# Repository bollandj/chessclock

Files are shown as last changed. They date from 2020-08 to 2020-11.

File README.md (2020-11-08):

# chessclock

An electronic chess clock with LED 7-segment displays, based around the ATmega88PA

# Current features include:

- Basic, increment, simple delay, Bronstein delay, hourglass and count up modes

- Start time and increment, delay etc. are fully programmable

- Sound (can be enabled or disabled)

- Adjustable display brightness

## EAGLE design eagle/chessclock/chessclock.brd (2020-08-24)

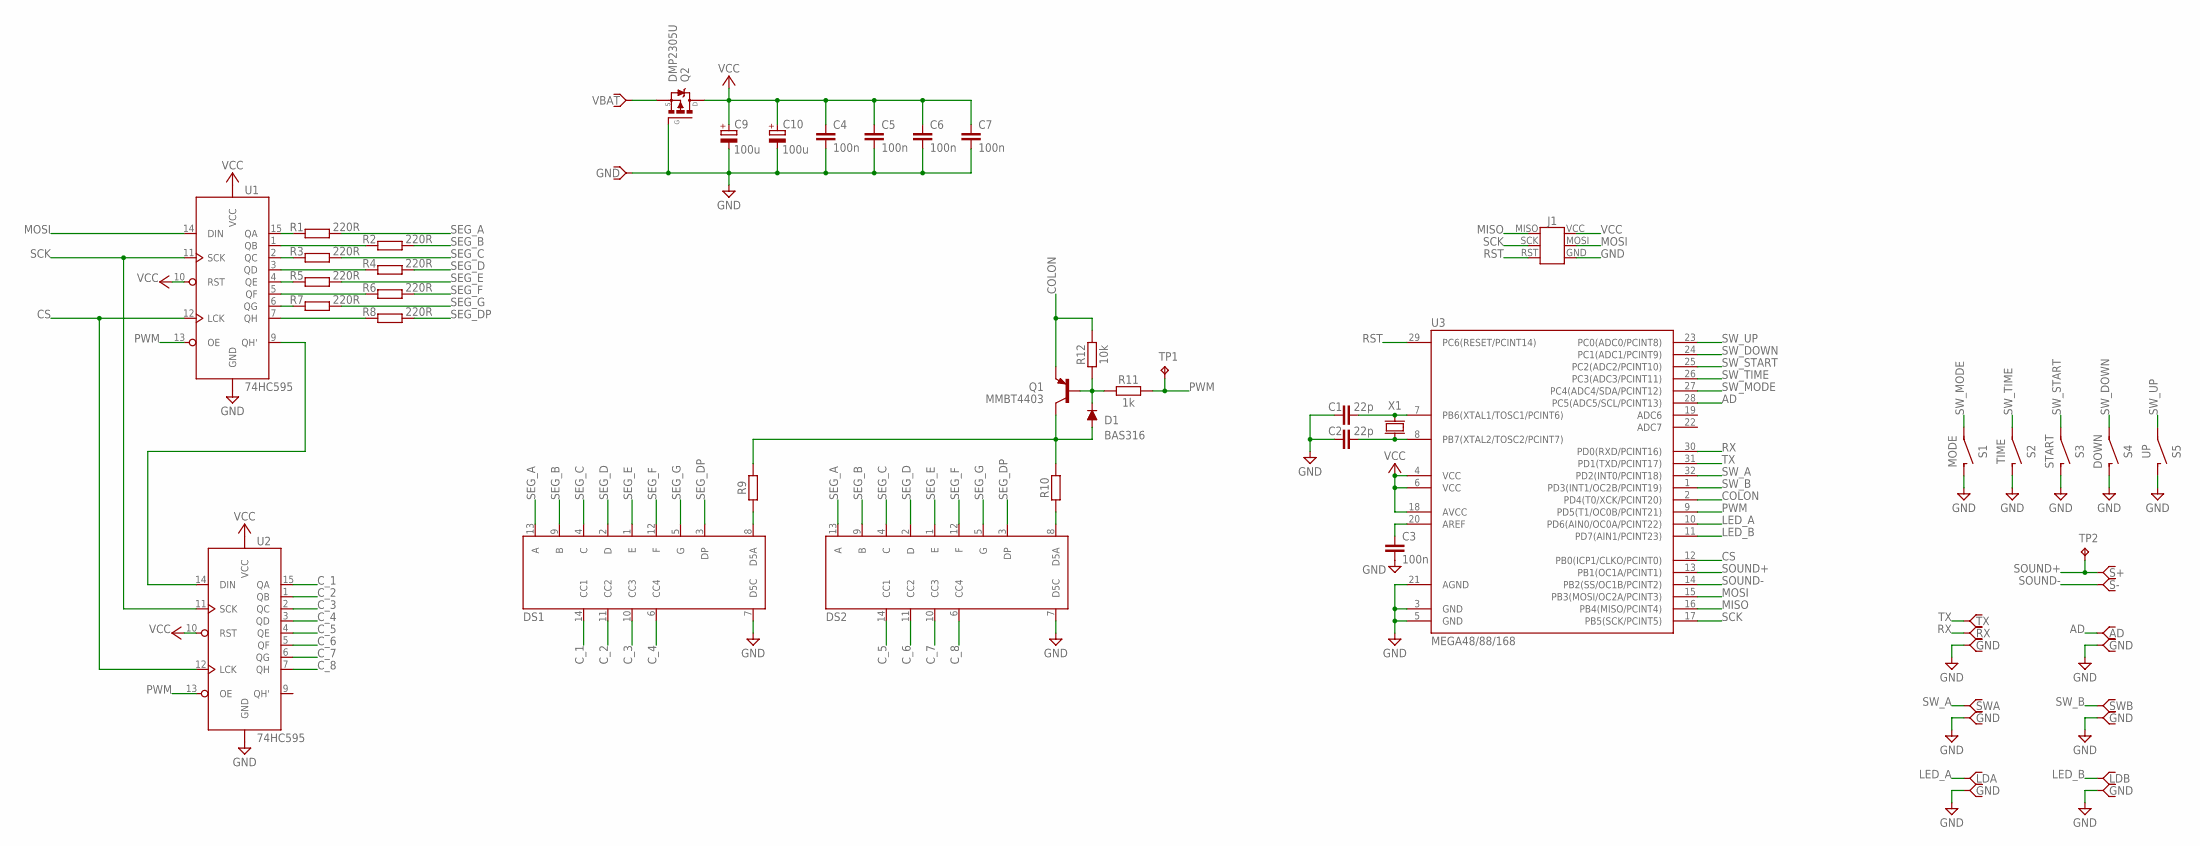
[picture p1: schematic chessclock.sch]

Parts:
C1, C2: 22p; C_0603
C3, C4, C5, C6, C7: 100n; C_0603
C9, C10: 100u; C_E_TH_FLAT_L_5MM
D1: BAS316; SOD323
DS1, DS2: SLR0564FR1C4BD-3.5
J1: AVRISPVERT; AVRISP
P1: SWA; CON_PIN_2MM
P2, P4, P6, P8, P9: GND; CON_PIN_2MM
P3: LDA; CON_PIN_2MM
P5: SWB; CON_PIN_2MM
P7: LDB; CON_PIN_2MM
P10: VBAT; CON_PIN_2MM
P11: S+; CON_PIN_2MM
P12: S-; CON_PIN_2MM
P13, P16: GND; CON_PIN
P14: RX; CON_PIN
P15: TX; CON_PIN
P17: AD; CON_PIN
Q1: MMBT4403; SOT23
Q2: DMP2305U; SOT23
R1, R2, R3, R4, R5, R6, R7, R8: 220R; R_0603
R9, R10: RESISTOR0603; R_0603
R11: 1k; R_0603
R12: 10k; R_0603
S1: MODE; SPST_6X6MM
S2: TIME; SPST_6X6MM
S3: START; SPST_6X6MM
S4: DOWN; SPST_6X6MM
S5: UP; SPST_6X6MM
TP1, TP2: TPTP15R; TP15R
U1, U2: 74HC595; SOIC16
U3: MEGA48/88/168; TQFP32-08
X1: XTAL_32768HZ2X6; XTAL_2X6MM

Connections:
AD: P17.1, U3.28 (PC5(ADC5/SCL/PCINT13))
COLON: Q1.2 (E), R12.2, U3.2 (PD4(T0/XCK/PCINT20))
CS: U1.12 (LCK), U2.12 (LCK), U3.12 (PB0(ICP1/CLKO/PCINT0))
C_1: DS1.14 (CC1), U2.15 (QA)
C_2: DS1.11 (CC2), U2.1 (QB)
C_3: DS1.10 (CC3), U2.2 (QC)
C_4: DS1.6 (CC4), U2.3 (QD)
C_5: DS2.14 (CC1), U2.4 (QE)
C_6: DS2.11 (CC2), U2.5 (QF)
C_7: DS2.10 (CC3), U2.6 (QG)
C_8: DS2.6 (CC4), U2.7 (QH)
GND: C1.2, C2.2, C3.1, C4.1, C5.1, C6.1, C7.1, C9.-, C10.-, DS1.7 (D5C), DS2.7 (D5C), J1.GND (6), P2.1, P4.1, P6.1, P8.1, P9.1, P13.1, P16.1, Q2.1 (G), S1.3 (2), S1.4 (2), S2.3 (2), S2.4 (2), S3.3 (2), S3.4 (2), S4.3 (2), S4.4 (2), S5.3 (2), S5.4 (2), U1.8 (GND), U2.8 (GND), U3.3 (GND), U3.5 (GND), U3.21 (AGND)
LED_A: P3.1, U3.10 (PD6(AIN0/OC0A/PCINT22))
LED_B: P7.1, U3.11 (PD7(AIN1/PCINT23))
MISO: J1.MISO (1), U3.16 (PB4(MISO/PCINT4))
MOSI: J1.MOSI (4), U1.14 (DIN), U3.15 (PB3(MOSI/OC2A/PCINT3))
unnamed: C1.1, U3.7 (PB6(XTAL1/TOSC1/PCINT6)), X1.1
unnamed: C2.1, U3.8 (PB7(XTAL2/TOSC2/PCINT7)), X1.2
unnamed: R2.1, U1.1 (QB)
unnamed: R1.1, U1.15 (QA)
unnamed: R3.1, U1.2 (QC)
unnamed: D1.A, Q1.3 (C), R9.2, R10.2
unnamed: D1.C, Q1.1 (B), R11.1, R12.1
unnamed: C3.2, U3.20 (AREF)
unnamed: R5.1, U1.4 (QE)
unnamed: R4.1, U1.3 (QD)
unnamed: R6.1, U1.5 (QF)
unnamed: R7.1, U1.6 (QG)
unnamed: R8.1, U1.7 (QH)
unnamed: U1.9 (QH'), U2.14 (DIN)
unnamed: DS2.8 (D5A), R10.1
unnamed: DS1.8 (D5A), R9.1
PWM: R11.2, TP1.TP, U1.13 (OE), U2.13 (OE), U3.9 (PD5(T1/OC0B/PCINT21))
RST: J1.RST (5), U3.29 (PC6(RESET/PCINT14))
RX: P14.1, U3.30 (PD0(RXD/PCINT16))
SCK: J1.SCK (3), U1.11 (SCK), U2.11 (SCK), U3.17 (PB5(SCK/PCINT5))
SEG_A: DS1.13 (A), DS2.13 (A), R1.2
SEG_B: DS1.9 (B), DS2.9 (B), R2.2
SEG_C: DS1.4 (C), DS2.4 (C), R3.2
SEG_D: DS1.2 (D), DS2.2 (D), R4.2
SEG_DP: DS1.3 (DP), DS2.3 (DP), R8.2
SEG_E: DS1.1 (E), DS2.1 (E), R5.2
SEG_F: DS1.12 (F), DS2.12 (F), R6.2
SEG_G: DS1.5 (G), DS2.5 (G), R7.2
SOUND+: P11.1, TP2.TP, U3.13 (PB1(OC1A/PCINT1))
SOUND-: P12.1, U3.14 (PB2(SS/OC1B/PCINT2))
SW_A: P1.1, U3.32 (PD2(INT0/PCINT18))
SW_B: P5.1, U3.1 (PD3(INT1/OC2B/PCINT19))
SW_DOWN: S4.1, S4.2 (1), U3.24 (PC1(ADC1/PCINT9))
SW_MODE: S1.1, S1.2 (1), U3.27 (PC4(ADC4/SDA/PCINT12))
SW_START: S3.1, S3.2 (1), U3.25 (PC2(ADC2/PCINT10))
SW_TIME: S2.1, S2.2 (1), U3.26 (PC3(ADC3/PCINT11))
SW_UP: S5.1, S5.2 (1), U3.23 (PC0(ADC0/PCINT8))
TX: P15.1, U3.31 (PD1(TXD/PCINT17))
VBAT: P10.1, Q2.2 (S)
VCC: C4.2, C5.2, C6.2, C7.2, C9.+, C10.+, J1.VCC (2), Q2.3 (D), U1.10 (RST), U1.16 (VCC), U2.10 (RST), U2.16 (VCC), U3.4 (VCC), U3.6 (VCC), U3.18 (AVCC)

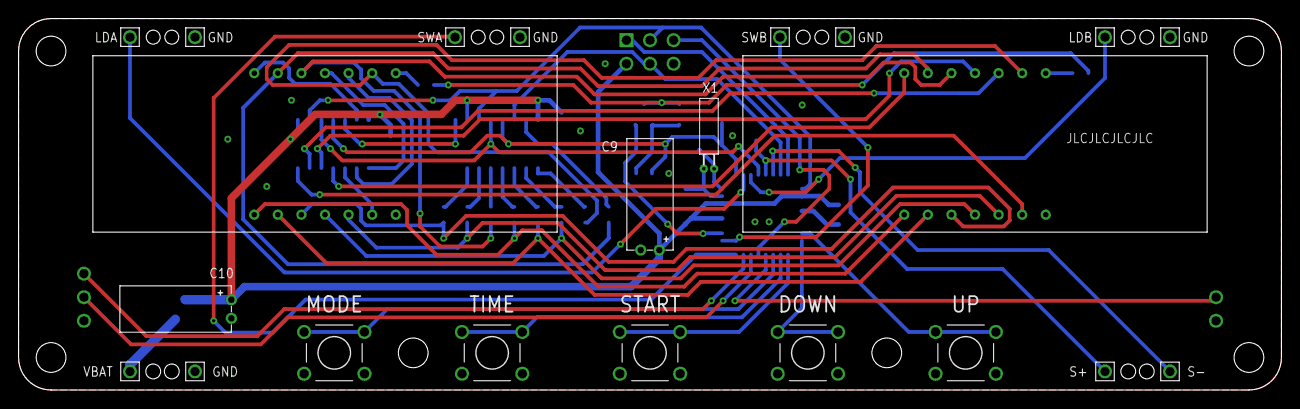
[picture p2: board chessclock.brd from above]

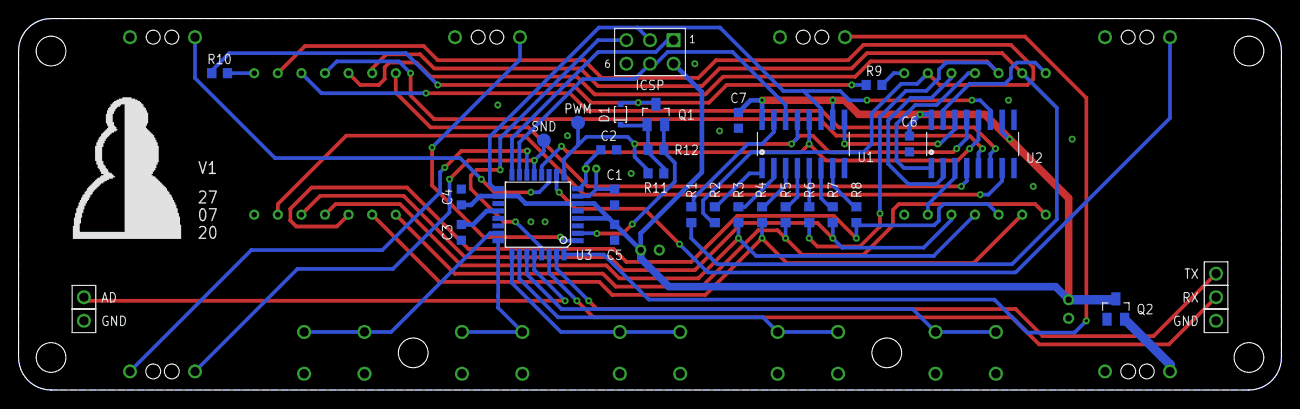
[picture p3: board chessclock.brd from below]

Board: 2 copper layers, 136.0 x 40.0 mm, 55 parts (33 on the bottom side), 56 nets.

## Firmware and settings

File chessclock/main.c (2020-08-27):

/*
 * chessclock.c
 *
 * Created: 03/07/2020 20:23:24
 * Author : Joshua
 */ 

#define F_CPU 8000000UL

#include <avr/io.h>
#include <avr/interrupt.h>
#include <util/delay.h>
#include <avr/pgmspace.h>

#include "display.h"
#include "keys.h"
#include "modes.h"
#include "settings.h"
#include "sound.h"

void init_timer(void)
{
	ASSR = 1<<AS2; // enable asynchronous mode
	
	TCCR2B |= 1<<CS20;  // /1 prescaler
	while (ASSR & 1<<TCR2BUB);     // wait for register update

	

	// TIFR2 = 1<<OCF2A;              // clear interrupt flag	
}

void reset(void)
{	
	/* reset time */
	for (uint8_t i = 0; i < 6; i++)
	{
		playerTime[PLAYER_A][i] = gameConfig.initialTime[i];
		playerTime[PLAYER_B][i] = gameConfig.initialTime[i];
	}

	/* reset ticks */
	playerTicks[PLAYER_A] = 127;
	playerTicks[PLAYER_B] = 127;
}

int main(void)
{			
	/* default to player A as white/starting */
	
	currentPlayer = PLAYER_A;
	
	state = IDLE;
	
	DDRD |= 1<<PD6 | 1<<PD7;
	PORTD &= ~(1<<PD7);
	PORTD |= 1<<PD6;
	
	load_config();
	
	reset();
	
	init_display(deviceConfig.brightness);
	init_keys();
	init_timer();
	init_sound();
	
	sei();
	
    while (1) 
    {					
		scan_keys();		
		
		if ((keyPressed & KEY_MASK) && deviceConfig.soundOn) beep(2);
		
		switch (state)
		{
			/* Idle */
			/* Ready to start a game */
			case IDLE:
			if (keyPressed & START_KEY)
			{
				start_callbacks[gameConfig.gameMode](); // gamemode-specific initialisation
				/* Start counting */
				TIMSK2 = 1<<TOIE2;			
				state = GAME_ACTIVE;
				break;
			}
			else if (keyPressed & MODE_KEY)
			{								
				state = EDIT_MODE;
				break;
			}
			else if (keyPressed & TIME_KEY)
			{
				timeEditCursor = 0;
				blinkMask[0] = 0xFF;
				blinkMask[4] = 0xFF;
								
				state = EDIT_TIME;
				break;
			}
				
			COLON_ON();		
			write_time(0);
			break;
			
			/* Time edit mode */
			/* Edit initial time for one or both players */
			case EDIT_TIME:
			if (keyPressed & START_KEY)
			{
				/* stop blinking */
				blinkMask[timeEditCursor] = 0x00;
				blinkMask[timeEditCursor+4] = 0x00;
				
				/* save settings */
				store_config();
				
				state = IDLE;
				break;	
			}
			else if (keyPressed & TIME_KEY)
			{
				blinkMask[timeEditCursor] = 0x00;
				blinkMask[timeEditCursor+4] = 0x00;
				
				timeEditCursor++;
				timeEditCursor &= 0x03;
				
				blinkMask[timeEditCursor] = 0xFF;
				blinkMask[timeEditCursor+4] = 0xFF;
			}
			else if (keyPressed & (UP_KEY | DOWN_KEY))
			{
				int8_t timeComponent;
				
				uint8_t limit = 5;                    // 9 for units, 5 for seconds
				if (timeEditCursor & 0x01) limit = 9; // even = units, odd = tens
				
				if (keyPressed & UP_KEY)
				{
					timeComponent = ++playerTime[PLAYER_A][timeEditCursor+2];
					if (timeComponent > limit) timeComponent = 0;
				}
				else
				{
					timeComponent = --playerTime[PLAYER_A][timeEditCursor+2];
					if (timeComponent < 0) timeComponent = limit;
				}
				
				gameConfig.initialTime[timeEditCursor+2] = timeComponent;
				
				playerTime[PLAYER_A][timeEditCursor+2] = timeComponent;
				playerTime[PLAYER_B][timeEditCursor+2] = timeComponent;
			}
			
			COLON_ON();	
			write_time(1);
			break;
			
			/* Edit game mode */
			/* Select between different clock modes */
			case EDIT_MODE:			
			if (keyPressed & START_KEY)
			{
				/* save settings */
				store_config();
				
				state = IDLE;
				break;
			}
			else if (keyPressed & MODE_KEY)
			{			
				state++;
				break;
			}						
			else if (keyPressed & UP_KEY)
			{			
				if (gameConfig.gameMode == NUM_MODES-1) gameConfig.gameMode = 0;
				else gameConfig.gameMode++;
			}
			else if (keyPressed & DOWN_KEY)
			{
				
				if (gameConfig.gameMode == 0) gameConfig.gameMode = NUM_MODES-1;
				else gameConfig.gameMode--;
			}
				
			COLON_OFF();		
			write_string(settingsMenuNames[state], 0, 4);		
			write_string(gameTypeNames[gameConfig.gameMode], 4, 8);
			break;
			
			/* Edit time increment/delay */
			/* Change increment or delay (simple/Bronstein modes) time */
			case EDIT_DELAY:
			if (keyPressed & START_KEY)
			{
				/* save settings */
				store_config();
				
				state = IDLE;
				break;
			}
			else if (keyPressed & MODE_KEY)
			{		
				state++;
				break;
			}
			else if (keyPressed & UP_KEY)
			{
				if      (gameConfig.delay < 20)  gameConfig.delay++;
				else if (gameConfig.delay < 45)  gameConfig.delay += 5;
				else if (gameConfig.delay < 60)  gameConfig.delay += 15; 
				else if (gameConfig.delay < 120) gameConfig.delay += 30; 	
			}
			else if (keyPressed & DOWN_KEY)
			{
				if      (gameConfig.delay > 60) gameConfig.delay -= 30;
				else if (gameConfig.delay > 45) gameConfig.delay -= 15;
				else if (gameConfig.delay > 20) gameConfig.delay -= 5;
				else if (gameConfig.delay > 0)  gameConfig.delay--; 	
			}
				
			COLON_OFF();		
			write_string(settingsMenuNames[state], 0, 4);
			write_number_8(gameConfig.delay, 4);
			break;
			
			/* Edit display brightness */
			/* Change PWM value */
			case EDIT_BRIGHTNESS:
			if (keyPressed & START_KEY)
			{
				/* save settings */
				store_config();
				
				state = IDLE;
				break;
			}
			else if (keyPressed & MODE_KEY)
			{				
				state++;
				break;
			}
			else if (keyPressed & UP_KEY)
			{
				if (deviceConfig.brightness < 10) deviceConfig.brightness++;
				OCR0B = deviceConfig.brightness << 2;	
			}
			else if (keyPressed & DOWN_KEY)
			{
				if (deviceConfig.brightness > 1) deviceConfig.brightness--;
				OCR0B = deviceConfig.brightness << 2;	
			}
			
			COLON_OFF();
			write_string(settingsMenuNames[state], 0, 4);
			write_number_8(deviceConfig.brightness, 4);
			break;
			
			/* Edit sound */
			/* Turn sound on or off */
			case EDIT_SOUND:
			if (keyPressed & START_KEY)
			{
				/* save settings */
				store_config();
				
				state = IDLE;
				break;
			}
			else if (keyPressed & MODE_KEY)
			{				
				state = EDIT_MODE; // wrap around after last setting in list
				break;
			}
			else if (keyPressed & (UP_KEY | DOWN_KEY))
			{
				deviceConfig.soundOn++;	
				deviceConfig.soundOn &= 0x01;
				beep(2); // extra beep required here as sound was disabled at top of loop	
			}
			
			COLON_OFF();
			write_string(settingsMenuNames[state], 0, 4);
			write_string(offOnStrings[deviceConfig.soundOn], 4, 8);
			break;
			
			/* Game active */
			/* Clock is currently counting down */
			case GAME_ACTIVE:
			if (keyPressed & START_KEY)
			{
				TIMSK2 = 0x00;
				state = GAME_PAUSED;
				break;	
			}
			
			COLON_ON();
			write_time(0);
			break;
			
			/* Game paused */
			/* Clock countdown for both players is paused */
			case GAME_PAUSED:
			if (holdTimer >= holdTimerThreshold)
			{				
				reset();
				beep(12);
				state = IDLE;
				break;	
			}
			else if (keyPressed & START_KEY)
			{
				TIMSK2 = 1<<TOIE2;
				state = GAME_ACTIVE;
				break;
			}
			
			COLON_ON();
			write_time(0);
			break;
			
			/* Game finished */
			/* One player's time has run out */
			case GAME_FINISHED:
			if (holdTimer >= holdTimerThreshold)
			{
				reset();
				beep(12);
				state = IDLE;
				break;
			}
			
			COLON_ON();
			write_time(0);
			break;
		}
							
		update_blink();
		update_beep();
		
		_delay_ms(15);				
    }
}

/* Player A's button */
ISR(INT0_vect) 
{	
	on_switch_interrupt(PLAYER_A);	
}

/* Player B's button */
ISR(INT1_vect)
{
	on_switch_interrupt(PLAYER_B);
}

ISR(TIMER2_OVF_vect)
{	
	tick_callbacks[gameConfig.gameMode]();				
}

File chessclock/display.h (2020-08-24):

/*
 * display.h
 *
 * Created: 04/07/2020 13:46:35
 *  Author: Joshua
 */ 


#ifndef DISPLAY_H_
#define DISPLAY_H_

#include <avr/io.h>
#include <avr/interrupt.h>
#include <avr/pgmspace.h>

#define SPI_DDR  DDRB
#define SPI_PORT PORTB

#define SCK  PB5
#define MOSI PB3
#define SS   PB2
#define CS   PB0

inline void COLON_ON()  {PORTD |= 1<<PD4;}
inline void COLON_OFF() {PORTD &= ~(1<<PD4);}

extern uint8_t hmms;

extern volatile uint8_t displayBuffer[8];

extern volatile uint8_t blinkOsc[8];
extern volatile uint8_t blinkMask[8];

extern uint8_t blinkTimer;
extern const uint8_t blinkThreshold;

extern const uint8_t sevenSeg[38];

void init_display(uint8_t brightness);
void update_blink(void);

void write_time(uint8_t edit);
void write_char(uint8_t chr, uint8_t pos);
void write_string(const char *str, uint8_t start, uint8_t end);
void write_number_8(uint8_t num, uint8_t start);


#endif /* DISPLAY_H_ */

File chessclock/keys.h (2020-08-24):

/*
 * keys.h
 *
 * Created: 04/07/2020 16:27:25
 *  Author: Joshua
 */ 


#ifndef KEYS_H_
#define KEYS_H_

#include <avr/io.h>

#define KEY_PORT PORTC
#define KEY_PIN  PINC

#define MODE_KEY  1<<PC4
#define TIME_KEY  1<<PC3
#define START_KEY 1<<PC2
#define DOWN_KEY  1<<PC1
#define UP_KEY    1<<PC0

#define KEY_MASK (MODE_KEY | TIME_KEY | START_KEY | DOWN_KEY | UP_KEY)

/* detect long presses of start/pause key */
extern uint8_t holdTimer;
extern const uint8_t holdTimerThreshold;

uint8_t keyState;
uint8_t lastKeyState;
uint8_t keyPressed;
uint8_t keyReleased;


void init_keys(void);
void scan_keys(void);


#endif /* KEYS_H_ */

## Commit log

2020-07-08 Fully switched time data structure from struct to array
2020-07-11 Added basic sound and integrated display blinking with display multiplex interrupt
2020-07-14 Added timer reset
2020-07-14 Added support for future display brightness PWM
2020-07-14 Switched to software 7-seg decoding to prepare for eventual shift register-based multiplexing
2020-08-24 Added CAD files, shift register and colon PWM support
    [chessclock.brd, chessclock.sch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]
2020-08-24 Removed Debug folder, switched to callback-based interrupts for greater flexibility, simplified current player status tracking
